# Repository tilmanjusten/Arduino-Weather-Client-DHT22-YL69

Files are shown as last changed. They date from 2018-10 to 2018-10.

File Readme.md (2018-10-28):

# Weather at Home Client: Temperature, Humidity and Soil Moisture

Get temperature and humidity from DHT22 and moisture from YL69 and send 
via 433MHz interface to the Smart Home Server.  
This project runs on an Arduino Nano. It should run on other Arduinos too.

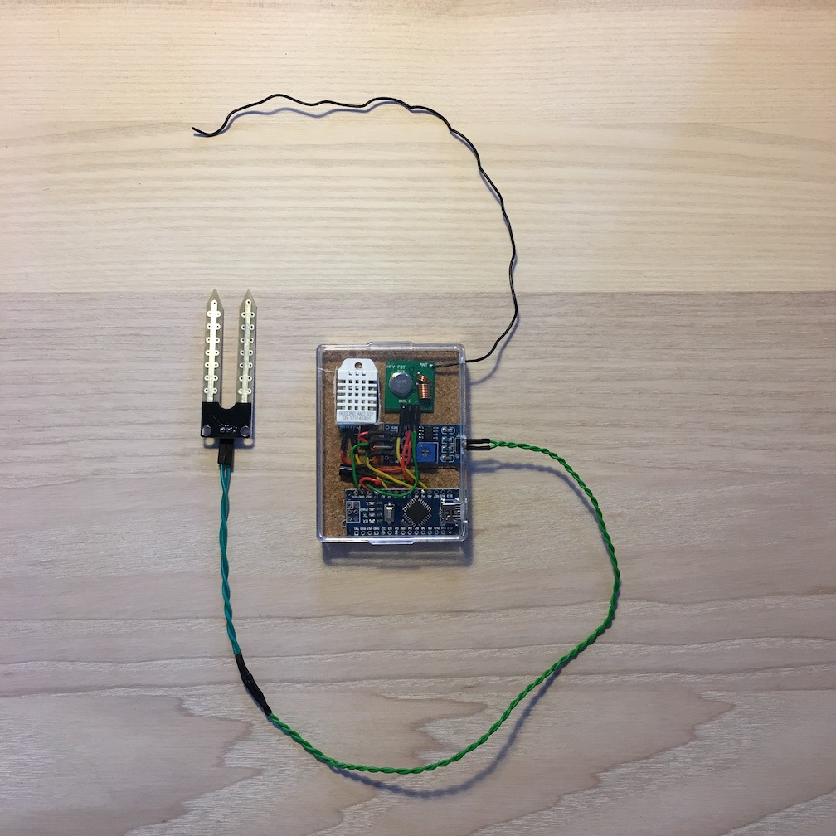
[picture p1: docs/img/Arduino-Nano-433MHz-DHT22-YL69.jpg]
Assembled Sensor Client


## Features

- Get 3 minutes temperature average
- Get 3 minutes humidity average
- Optional soil moisture every 30 minutes
- Send data via 433.92MHz transmitter
- Reduces overall power comsumption
- Prevents corrosion of the soil moisture sensor

## Development

Enable verbose logging: set ``MODE`` to ``MODE_DEVELOPMENT``

### Dependencies

Required libraries:

- Adafruit Unified Sensor
- DHT sensor library
- Low-Power

## Deployment

1. Disable verbose logging: set ``MODE`` to ``MODE_PRODUCTION``
1. Flash device

## Hardware

### Parts

- Arduino (Nano, Mini, Uno, ...)
- DHT22 for temperature and humidity
- 220 Ohm resistor
- Optional: YL69 for moisture
- Optional NPN transistor (enable/disable YL69 to prevent corrosion)
- 433MHz transmitter
- Wires
- USB cable USB-A to USB Micro
- Power supply (1A)
- Plastic case (~&nbsp;70&times;55&times;15&nbsp;mm)
- Cork board

### Wiring

[See Fritzing Sketch](docs/Arduino-Nano-433MHz-DHT22-YL69_Wiring.fzz)

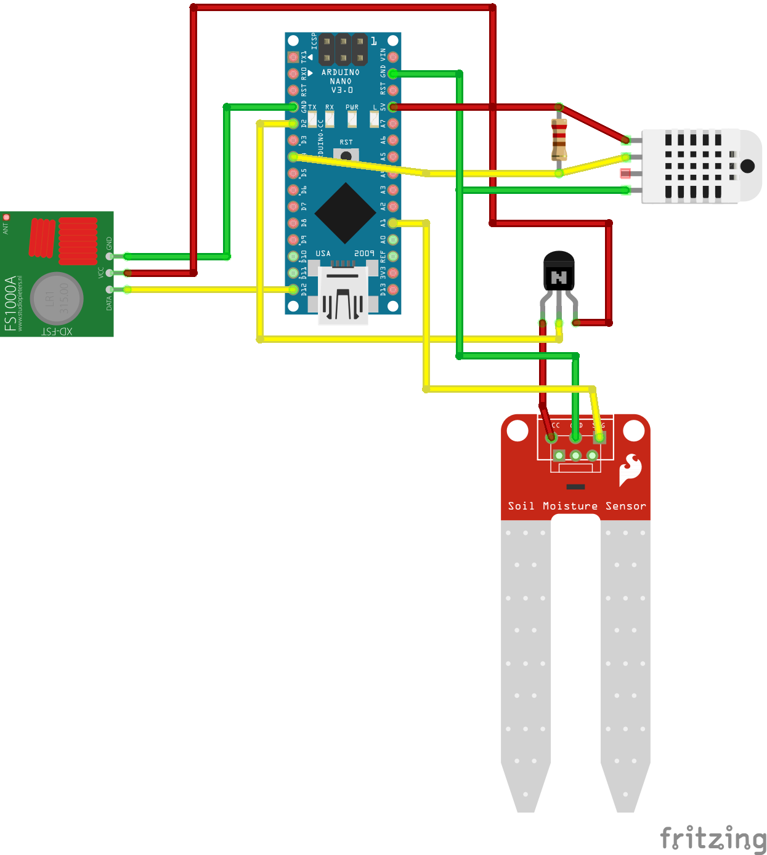
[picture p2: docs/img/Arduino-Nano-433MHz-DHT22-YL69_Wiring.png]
Fritzing Sketch


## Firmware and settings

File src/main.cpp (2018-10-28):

// v2.2.0

#include <DHT.h>
#include <RH_ASK.h>
#include <SPI.h> // Not actually used but needed to compile
#include <Log.h>
#include <LowPower.h>

#ifndef MODE_PRODUCTION
#define MODE_PRODUCTION 0x0
#endif
#ifndef MODE_DEVELOPMENT
#define MODE_DEVELOPMENT 0x1
#endif
#ifndef MODE
#define MODE MODE_PRODUCTION
#endif

#define ENABLE_YL69 0x1

// Receiver pin
#define RXPIN 11
// Transmitter pin
#define TXPIN 12

#define DHTPIN 4 // what digital pin we're connected to
//#define ID "THOR" // ok 1010271705 v2.2.0, was ODIN => THOR (Schlafzimmer)
//#define ID "AMUN" // ok 1810261800 v2.2.0, was INKE => AMUN (Badezimmer)
#define ID "ZEUS" // ok 1010271710 v2.2.0, was PURL => ZEUS (Wohnzimmer)
#define MSGFORMAT_DHT "%s0HU%03dTE%+04d"
#define DELAY_DHT 2750

#ifdef ENABLE_YL69
#define DELAY_YL69 1800000 // 30 Minutes
#define MSGFORMAT_YL69 "%sMO%04dMV%+04d"
#define YL69PIN PIN_A1
#define YL69PIN_VCC 2
#endif

#define DHTTYPE DHT22 // DHT 22  (AM2302), AM2321

RH_ASK driver(2000, RXPIN, TXPIN);
Log l(MODE == MODE_PRODUCTION ? LOG_MODE_SILENT : LOG_MODE_VERBOSE);

float prevHumidity = 0;
float prevTemperature = 0;
int humidities[60] = {};
int temperatures[60] = {};
int valueIterator = 0;
int valuesNum = sizeof(humidities) / sizeof(int);
bool initialized_dht = false;
bool reinitialized_dht = false;
long timerDebugDHT = 0;
long timerDHT = 0;

#ifdef ENABLE_YL69
long timerYL69 = 0;
bool initialized_yl69 = false;
#endif

// Connect pin 1 (on the left) of the sensor to +5V
// NOTE: If using a board with 3.3V logic like an Arduino Due connect pin 1
// to 3.3V instead of 5V!
// Connect pin 2 of the sensor to whatever your DHTPIN is
// Connect pin 4 (on the right) of the sensor to GROUND
// Connect a 10K resistor from pin 2 (data) to pin 1 (power) of the sensor

// Initialize DHT sensor.
// Note that older versions of this library took an optional third parameter to
// tweak the timings for faster processors.  This parameter is no longer needed
// as the current DHT reading algorithm adjusts itself to work on faster procs.
DHT dht(DHTPIN, DHTTYPE);

void sleep(period_t sleepTime)
{
  LowPower.idle(
      sleepTime,
      ADC_OFF,
      TIMER2_OFF,
      TIMER1_OFF,
      TIMER0_ON,
      SPI_OFF,
      USART0_OFF,
      TWI_OFF);
}

void printValuesDHT(char *msgBuffer, int h, int t)
{
  l.l((millis() - timerDebugDHT) / 1000);
  l.l("s -> ");
  l.l("HU ");
  l.l(h);
  l.l(" TE ");
  l.l(t);
  l.l(" Message: ");
  l.l(msgBuffer);
  l.ln();

  timerDebugDHT = millis();
}

void handleDHT()
{
  // Reading temperature or humidity takes about 250 milliseconds!
  // Sensor readings may also be up to 2 seconds 'old' (its a very slow sensor)
  int h = dht.readHumidity();
  // Read temperature as Celsius (the default)
  int t = dht.readTemperature();
  int hSum = 0;
  int tSum = 0;
  int hAvg;
  int tAvg;
  float hAvgFloat;
  float tAvgFloat;

  // Check if any reads failed and exit early (to try again).
  if (isnan(h) || isnan(t))
  {
    l.ln("Failed to read from DHT sensor!");

    return;
  }

  humidities[valueIterator] = h;
  temperatures[valueIterator] = t;
  valueIterator++;

  // reset counter
  if (valueIterator == valuesNum)
  {
    // set initialized after first iteration loop
    if (initialized_dht == false)
    {
      l.ln("First iteration loop completed. Begin to send data.");

      initialized_dht = true;
    }

    if (initialized_dht == true && reinitialized_dht == false)
    {
      l.ln("Update full set of measurements.");

      reinitialized_dht = true;
    }

    valueIterator = 0;
  }

  // calc average values
  for (int i = 0; i < valuesNum; i++)
  {
    hSum += humidities[i];
    tSum += temperatures[i];
  }

  hAvgFloat = hSum / valuesNum;
  tAvgFloat = tSum / valuesNum;
  hAvg = ceil(hAvgFloat);
  tAvg = ceil(tAvgFloat);

  // send value when changed (>= 1.00°C / >= 1.00%) and first set of measurements is complete
  //  if (reinitialized && (abs(hAvgFloat - prevHumidity) >= 1 || abs(tAvgFloat - prevTemperature) >= 1)) {
  // send value every full set (~ once every 3 minutes)
  if (reinitialized_dht)
  {
    char msgBuffer[16];
    int n = sprintf(msgBuffer, MSGFORMAT_DHT, ID, hAvg, tAvg);

#if MODE == MODE_PRODUCTION
    driver.send((uint8_t *)msgBuffer, n);
    driver.waitPacketSent();
#endif

    // update storage
    prevHumidity = hAvgFloat;
    prevTemperature = tAvgFloat;

    // get full set of measurements before sending again
    reinitialized_dht = false;

    printValuesDHT(msgBuffer, hAvg, tAvg);
  }
}

#ifdef ENABLE_YL69
void handleYL69()
{
  l.l("Enable sensor... ");
  digitalWrite(YL69PIN_VCC, HIGH);

  delay(50);

  l.l("Read data... ");
  int analog = analogRead(YL69PIN);
  int val = map(analog, 0, 1023, 100, 0);

  l.l("Disable sensor... ");
  digitalWrite(YL69PIN_VCC, LOW);

  // Send via RadioHead
  char msgBuffer[16];
  int n = sprintf(msgBuffer, MSGFORMAT_YL69, ID, analog, val);

#if MODE == MODE_PRODUCTION
  driver.send((uint8_t *)msgBuffer, n);
  driver.waitPacketSent();
#endif

  // Debug output
  l.l("Analog: ");
  l.l(analog);
  l.l(", Value: ");
  l.l(val);
  l.l("%");
  l.l(", Message: ");
  l.l(msgBuffer);
  l.ln();
}
#endif

void setup()
{
  Serial.begin(9600);
  l.l("DHT22 Humidity and Temperature: ");
  l.ln(ID);
  l.l("Send average of ");
  l.l(valuesNum);
  l.ln(" measurements.");

  // DHT22
  dht.begin();

#ifdef ENABLE_YL69
  // YL69
  pinMode(YL69PIN, INPUT);
  pinMode(YL69PIN_VCC, OUTPUT);

  digitalWrite(YL69PIN_VCC, LOW);
#endif

  delay(100);

  if (!driver.init())
  {
    l.ln("Failed to initialize RadioHead!");
  }
}

void loop()
{
  sleep(SLEEP_2S);

  // every loop may take 3s => 3s * 60 values = send value every 3 min => ~480 values per day
  if (millis() - timerDHT > DELAY_DHT)
  {
    handleDHT();

    timerDHT = millis();
  }

#ifdef ENABLE_YL69
  // every loop may take 3s => 3s * 60 values = send value every 3 min => ~480 values per day
  if (initialized_yl69 == false || millis() - timerYL69 > DELAY_YL69)
  {
    handleYL69();

    timerYL69 = millis();
    initialized_yl69 = true;
  }
#endif
}

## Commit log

2018-10-21 refactor script for both sensors
2018-10-26 reduce power comsumption
